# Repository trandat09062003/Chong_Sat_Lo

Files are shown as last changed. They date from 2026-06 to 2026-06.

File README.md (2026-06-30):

# Hệ thống cảnh báo sạt lở đất (Chong_Sat_Lo)

Dự án nghiên cứu thiết kế và chế tạo trạm đo thực địa cảnh báo sớm nguy cơ sạt lở đất tại các vùng đồi núi (đặc biệt áp dụng thử nghiệm tại khu vực Dốc Cun và Đèo Thung Khe, Quốc lộ 6, tỉnh Hòa Bình) dựa trên các thông số môi trường và động học đất.

Hệ thống bao gồm các trạm đo thực địa (mạch phát) thu thập dữ liệu đa cảm biến, tự động đánh giá nguy cơ sạt lở và gửi thông tin không dây qua sóng LoRa khoảng cách xa về trạm giám sát (mạch thu).

---

## 1. Thành phần hệ thống

### Trạm đo thực địa (Mạch Phát - Transmit)
- **MCU trung tâm:** ESP32 DevKit V1 (30 chân).
- **Cảm biến địa chấn & động học:** MPU6050 đo rung chấn, góc nghiêng và độ dịch chuyển cấu trúc đất.
- **Cảm biến môi trường:** Cảm biến độ ẩm đất (giám sát độ bão hòa nước) và cảm biến lượng mưa.
- **Khối hiển thị:** Màn hình LCD 20x4 giao tiếp I2C.
- **Khối truyền thông:** Module LoRa SX1278 (E32/AS32 UART) truyền xa.
- **Khối cảnh báo:** Còi hú cảnh báo tại chỗ kích bằng transistor C1815.
- **Khối nguồn:** Pin Lithium 18650 sạc bằng năng lượng mặt trời (tấm pin 5V - 10W qua mạch sạc TP4056) và cầu phân áp đo dung lượng pin gửi về trung tâm.

### Trạm giám sát (Mạch Thu - Receive)
- **MCU trung tâm:** ESP32 nhận dữ liệu LoRa gửi về.
- **Hiển thị tại chỗ:** Màn hình LCD 20x4 I2C hiển thị trực quan thông số nhận được từ trạm phát.
- **Dashboard Web:** ESP32 mạch thu tự phát mạng Wi-Fi Access Point cục bộ (`ESP32_Gateway_AP`) và khởi chạy Web Server hiển thị giao diện dashboard giám sát thời gian thực, có chế độ chớp đỏ và còi báo động trên web khi trạm phát rơi vào trạng thái nguy hiểm.

---

## 2. Sơ đồ kết nối phần cứng (Theo code thực tế)

### Mạch Phát (Transmit Node)
| Thiết bị / Chân kết nối | Chân ESP32 | Ghi chú |
| --- | --- | --- |
| **Cảm biến độ ẩm đất (Analog)** | GPIO 34 | Đọc giá trị ADC độ bão hòa nước |
| **Cảm biến độ ẩm đất (Digital)** | GPIO 35 | Phát hiện ngưỡng khô/ẩm |
| **Cảm biến mưa (Analog)** | GPIO 33 | Đọc giá trị ADC cường độ mưa |
| **Cảm biến mưa (Digital)** | GPIO 32 | Phát hiện có mưa hay không |
| **Cảm biến MPU6050 (I2C SDA)** | GPIO 21 | Bus dữ liệu I2C dùng chung với LCD |
| **Cảm biến MPU6050 (I2C SCL)** | GPIO 22 | Bus xung clock I2C |
| **Cảm biến MPU6050 (INT)** | GPIO 4 | Chân ngắt tín hiệu địa chấn |
| **Màn hình LCD 20x4 I2C** | GPIO 21 (SDA), GPIO 22 (SCL) | Địa chỉ mặc định: 0x27 |
| **Còi hú (Buzzer)** | GPIO 25 | Kích hoạt còi hú mức cao (HIGH) |
| **Đo điện áp Pin** | GPIO 12 | Đọc qua cầu phân áp R1=100k, R2=100k |
| **LoRa E32/AS32 (RX)** | GPIO 16 | Nối với chân TX của module LoRa |
| **LoRa E32/AS32 (TX)** | GPIO 17 | Nối với chân RX của module LoRa |
| **LoRa E32/AS32 (M0/M1/AUX)**| GPIO 26 / 27 / 14 | Điều khiển chế độ hoạt động của LoRa |

### Mạch Thu (Receive Node)
| Thiết bị / Chân kết nối | Chân ESP32 | Ghi chú |
| --- | --- | --- |
| **LoRa E32/AS32 (RX)** | GPIO 16 | Nối với chân TX của module LoRa |
| **LoRa E32/AS32 (TX)** | GPIO 17 | Nối với chân RX của module LoRa |
| **LoRa E32/AS32 (M0/M1/AUX)**| GPIO 25 / 26 / 27 | Điều khiển chế độ hoạt động |
| **LCD 20x4 I2C** | GPIO 21 (SDA), GPIO 22 (SCL) | Hiển thị thông số nhận được từ RF |

---

## 3. Cấu trúc thư mục dự án

```text
├── Transmit/                  # Mã nguồn trạm phát đo thực địa (Transmit.ino)
├── Receive/                   # Mã nguồn trạm thu (Receive.ino)
├── PCB_Tra/                   # Bản vẽ Altium Designer trạm phát (Schematic & PCB)
├── PCB_Rec/                   # Bản vẽ Altium Designer trạm thu (Schematic & PCB)
├── libraries/                 # Thư viện Arduino đóng gói dùng chung cho dự án
├── Test_*/                    # Các thư mục chứa mã nguồn test độc lập linh kiện
│   ├── Test_Buzzer/
│   ├── Test_LoRa_E32/
│   └── Test_MPU_LCD/
├── yêu cầu.txt                # Tài liệu tóm tắt yêu cầu dự án
└── Báo cáo tuần 5.docx        # Báo cáo tiến độ và kết quả thực hiện tuần 5
```

---

## 4. Logic phân cấp cảnh báo (Risk Evaluation)

Thuật toán đánh giá rủi ro kết hợp các ngưỡng giá trị môi trường và gia tốc/góc nghiêng để đưa ra 3 cấp độ cảnh báo:

1. **Cấp độ 0 (AN TOÀN - SAFE):** 
   - Đất ổn định, không mưa, góc nghiêng và độ rung lắc dưới ngưỡng cảnh báo.
2. **Cấp độ 1 (CẢNH BÁO SỚM - WARNING):**
   - Xảy ra khi độ ẩm đất tăng cao (`>= 70%`), mưa kéo dài (`>= 60%`) hoặc xuất hiện rung lắc nhẹ (`>= 0.8 m/s²`).
3. **Cấp độ 2 (NGUY HIỂM - DANGER):**
   - Phát hiện sụt lún hoặc trượt đất tức thời khi góc nghiêng lệch quá ngưỡng (`>= 15 độ`), hoặc đất đã bão hòa nước cực cao (`>= 85%`) kèm rung chấn địa chất mạnh (`>= 1.5 m/s²`).
   - Hệ thống tự kích hoạt còi hú cảnh báo tại chỗ đồng thời gửi tín hiệu khẩn cấp về trạm thu qua LoRa.

---

## 5. Hướng dẫn cài đặt và sử dụng

### Cài đặt phần mềm
1. Sao chép các thư mục con trong thư mục `libraries/` của dự án vào thư mục `libraries` trong thư mục làm việc của Arduino IDE trên máy tính.
2. Mở file mã nguồn `Transmit/Transmit.ino` (cho mạch phát) hoặc `Receive/Receive.ino` (cho mạch thu) bằng Arduino IDE.
3. Chọn đúng board `DOIT ESP32 DEVKIT V1` (hoặc `ESP32 Dev Module`) và cổng COM để nạp chương trình.

### Vận hành hệ thống
1. **Trạm phát:** Đặt thiết bị cố định trên cọc cắm sâu dưới đất tại khu vực cần theo dõi. Khi cấp nguồn, hệ thống sẽ tự động đo đạc góc cân bằng ban đầu (Pitch/Roll) làm mốc so sánh.
2. **Trạm thu:** Đặt tại phòng điều khiển hoặc khu vực trung tâm. Trạm thu sẽ liên tục cập nhật dữ liệu hiển thị lên LCD.
3. **Giám sát qua Web:** Kết nối điện thoại hoặc máy tính vào mạng Wi-Fi `ESP32_Gateway_AP` (mật khẩu: `123456789_landslide`). Truy cập địa chỉ IP `192.168.4.1` trên trình duyệt để xem giao diện dashboard.

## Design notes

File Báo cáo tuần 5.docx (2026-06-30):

1. Sơ đồ khối

Khối nguồn (tấm pin NLMT)

Khối cảm biến

Mạch đo dung luọng pin

Khối xử lý

(ESP32)

Khối truyền tin (loRa)

Khối hiển thị

Khối cảnh báo

Trung tâm giám sát và điều hành

Tín hiệu nối cứng

Tín hiệu không dây

Đường nguồn

- Khối nguồn: cấp điện cho toàn bộ hệ thống trên sơ đồ có các mức điện áp sau

+ 3.3V: dùng cho khối cảm biến, khối xử lý, khối truyền tin

+ 5V: dùng cho khối cảm biến khối hiển thị khối cảnh báo và 1 số thiết bị khác

- Khối cảm biến: sau khi đo độ ẩm đất, lượng mưa và độ rung xong sẽ gửi tín hiệu đến khối xử lý
- Khối xử lý: sau khi đã nhận dữ liệu từ khối cảm biến sẽ tiến hành đánh giá, xử lý dựa trên kết quả đo được và đưa ra cảnh báo
- Mạch đo dung lượng pin: giúp trung tâm giám sát và điều hành biết được pin còn lại bao nhiêu % và điện áp của pin như nào
- Khối hiển thị: hiển thị dữ liệu cảm biến do được và điện áp pin
- Khối lora: truyền dữ liệu cảm biến dung lượng pin trạng thái cảnh báo về trung tâm giám sát và nguọc lại
- Khói cảnh báo: cảnh báo khu vực có nguy cơ sạt lở
- Trung tâm giám sát điều hành: nhận tất cả dữ liệu trên đưa ra cảnh báo và sợ tán người dân phương tiện trước khi sảy ra sạt lở

Giao tiếp giữa các khối

- Khối cảm biến giao tiếp với ESP32

+ cảm biến lượng mưa vs esp32 qua Analog/Digital

+ cảm biến độ ẩm đất vs esp32 qua Analog

+ cẩm biến rung(MPU6050) vs esp32 qua I2C

- Khối truyền tin lora giao tiếp vs esp32 qua SPI
- Khối hiển thị giao tiếp vs esp32 qua I2C
- Khối cảnh báo giao tiếp vs esp32 qua Digital
- Mạch đo pin giao tiếp vs esp32 qua
2. Bảng dự toán và chức năng của linh kiện

STT | Tên linh kiện | Chức năng trong đồ án | Số lượng | Đơn giá (VNĐ) | Thành tiền (VNĐ)
1 | ESP32 | Vi điều khiển trung tâm, xử lý dữ liệu và kết nối. | 2 | 120.000 | 240.000
2 | Module LoRa SX1278 (433MHz) | Truyền/Nhận dữ liệu không dây khoảng cách xa. | 2 | 200.000 | 400.000
3 | Cảm biến lượng mưa | Đo cường độ và lượng mưa rơi xuống. | 1 | 75.000 | 75.000
4 | Cảm biến độ ẩm đất | Giám sát độ bão hòa nước của đất vùng núi. | 1 | 75.000 | 75.000
5 | Cảm biến MPU6050 | Đo độ rung, độ nghiêng và dịch chuyển của đất. | 1 | 90.000 | 90.000
6 | Tấm pin năng lượng mặt trời (5V-10W) | Cung cấp năng lượng cho hệ thống ngoài thực địa. | 2 | 200.000 | 400.000
7 | Pin Lithium 18650 & Mạch sạc TP4056 | Lưu trữ năng lượng và quản lý sạc/xả pin. | 2 | 60.000 | 120.000
8 | Còi hú cảnh báo | Phát tín hiệu cảnh báo tại chỗ cho người đi đường. | 1 | 55 .000 | 55.000
9 | Màn hình LCD 16x2 (I2C) | Hiển thị thông số môi trường tại trạm. | 1 | 150.000 | 150.000
10 | Phụ kiện khác | Bảo vệ hệ thống khỏi thời tiết và kết nối linh kiện. | 1 | 500.000 | 500.000

Tổng cộng: ~2.105.000VND

3. Tại sao lại dùng esp32 làm vđk trung tâm
- Hiệu năng mạnh, xử lý đa cảm biến tốt

+ ESP32 có CPU 32-bit, tốc độ cao (~240MHz)

+ Đọc nhiều cảm biến cùng lúc: mưa, độ ẩm đất, MPU6050 (rung)

- Tích hợp nhiều giao tiếp (rất quan trọng)

+ đọc MPU6050, LCD

+ giao tiếp SX1278 LoRa Module

- Tiết kiệm điện (có chế độ Deep Sleep)

+ Có thể giảm tiêu thụ xuống rất thấp khi không hoạt động

+ Phù hợp với hệ thống dùng pin năng lượng mặt trời

- Dù hiện tại không dùng WiFi, nhưng:

+ ESP32 đã tích hợp WiFi + Bluetooth sẵn Sau này có thể:

+ Gửi dữ liệu lên app

+ Kết nối IoT (Blynk, web server…)

+ Tận dụng hiệu năng, tiết kiệm điện và khả năng mở rộng IoT trong tương lai

4. Nghiên cứu mô hình dự báo khả năng sạt lở (các đầu vào, mô hình dự báo, tỷ lệ chính xác)
- Các đầu vào của hệ thống dự báo nên chia thành 3 nhóm:

+ Nhóm khí tượng:

• Lượng mưa (mm/h, mm/ngày)

• Thời gian mưa liên tục

+ Nhóm địa chất – môi trường

• Độ ẩm đất (%)

• Độ bão hòa nước trong đất

+ Nhóm động học (chuyển động)

• Gia tốc/rung động đất (từ MPU6050)

• Độ nghiêng địa hình (nếu có)

- Sử dụng mô hình ngưỡng cảnh báo (Threshold-based Model)
- Hệ thống sẽ đọc lượng mưa, độ ẩm đất, và độ rung sau đấy sẽ gửi dữ liệu về cho ESP32 kiểm tra kết hợp với thông số đo được từ nhiều lần sạt lở trước để đưa ra mức độ cảnh báo trung bình cho những lần sắp tới

+ Ví dụ mức trung bình:

• Mưa > 50 mm/ngày

• Độ ẩm đất > 70%

• Có rung bất thường

+ Nếu các thông số sau vượt mức trung bình trên hệ thống sẽ gửi tín hiệu cảnh báo sạt lở về trung tâm

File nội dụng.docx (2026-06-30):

1. Cảm biến địa chấn để giám sát động học đất

Tích hợp cảm biến địa chấn để giám sát động học đất

Để hệ thống cảnh báo sạt lở đạt được độ tin cậy cao, việc chỉ đo lường các thông số môi trường tĩnh (như lượng mưa hay độ ẩm đất) là chưa đủ, bởi chúng chỉ phản ánh các điều kiện tiền đề. Nhằm phát hiện trực tiếp các dấu hiệu sạt lở đang nhen nhóm, đề tài tiến hành bổ sung cảm biến quán tính 6 trục MPU6050 đóng vai trò như một cảm biến địa chấn (seismic sensor) cục bộ. Nhiệm vụ của khối này là giám sát liên tục các đặc trưng động học như sự dịch chuyển, rung chấn và đứt gãy vật lý của cấu trúc đất đá.

Giải pháp phần cứng và phương pháp đo lường:

- Lắp đặt thực địa: Module MPU6050 được gắn cố định bên trong một cọc quan trắc chuyên dụng và đóng ngập sâu xuống lớp đất chịu lực tại sườn dốc. Việc neo chặt khối cảm biến vào nền đất giúp thiết bị nhạy bén tuyệt đối với những dao động cơ học truyền qua khối đất.
- Giao tiếp dữ liệu: Cảm biến giao tiếp với bộ vi điều khiển trung tâm (ESP32) thông qua chuẩn nối tiếp I2C. Vi điều khiển được lập trình để liên tục lấy mẫu dữ liệu không gian 3 chiều với tần số cao, đảm bảo không bỏ sót bất kỳ rung động chớp nhoáng nào của nền đất.

Thuật toán xử lý tín hiệu và lọc nhiễu:

- Loại bỏ nhiễu môi trường: Dữ liệu gia tốc thô thu về ở thực địa thường bị lẫn các nhiễu cơ học không mong muốn (như sức gió tạt vào thân cọc lộ thiên hoặc chấn động từ phương tiện giao thông đi ngang qua). Để làm sạch dữ liệu, hệ thống kích hoạt bộ lọc thông thấp kỹ thuật số (DLPF) tích hợp sẵn bên trong cảm biến nhằm triệt tiêu các dải tần số nhiễu cao, chỉ giữ lại các dao động tần số thấp phản ánh đúng bản chất sự chuyển dịch của khối đất.
- Đánh giá mức độ rủi ro động học: Thay vì đánh giá rời rạc sự thay đổi trên từng trục tọa độ (X, Y, Z), vi điều khiển sẽ thuật toán hóa để tổng hợp các giá trị này lại, từ đó xác định được biên độ chuyển động tổng thể và độ lệch góc nghiêng thực tế của cọc quan trắc.
- Phát hiện bất thường: Ở trạng thái an toàn, cấu trúc đất ổn định, hệ thống cảm biến chỉ ghi nhận duy nhất tác động của gia tốc trọng trường và góc nghiêng được duy trì hằng số. Khi kết cấu đất ngậm đủ nước và bắt đầu có hiện tượng sụt lún, trượt hoặc nứt gãy bên trong, biên độ dao động tổng thể sẽ thay đổi đột ngột. Những biến thiên vượt qua dải sai số tĩnh cho phép này sẽ được hệ thống nhận diện là đặc trưng nguy hiểm, sau đó được trích xuất làm đầu vào cho mô hình dự báo học máy để xác định thời điểm kích hoạt báo động khẩn cấp.

2. Thu thập dữ liệu tình hình sạt lở tại địa phương cụ thể

Để hệ thống cảnh báo có tính ứng dụng thực tiễn cao và mô hình dự báo học máy hoạt động chính xác, việc xây dựng một bộ dữ liệu (dataset) dựa trên bối cảnh địa chất thực tế là yêu cầu bắt buộc. Đề tài lựa chọn phạm vi nghiên cứu và thu thập dữ liệu tại tuyến Quốc lộ 6, đoạn qua Dốc Cun và Đèo Thung Khe thuộc tỉnh Hòa Bình.

Đặc điểm địa chất khu vực nghiên cứu: Đây là tuyến giao thông huyết mạch cửa ngõ vùng Tây Bắc, có địa hình đồi núi chia cắt phức tạp và độ dốc sườn taluy rất lớn. Kết cấu đất đá tại khu vực này bị phong hóa mạnh, tơi xốp, hệ số rỗng lớn và có độ liên kết kém. Vào mùa mưa bão, khi lớp đất mặt ngậm nước đến mức bão hòa, trọng lượng khối trượt tăng lên đột biến trong khi lực ma sát nội suy giảm, biến khu vực này thành "điểm nóng" nhạy cảm, thường xuyên xảy ra sụt lún và sạt lở đất đá nghiêm trọng.

Quy trình và phương pháp thu thập dữ liệu: Do không có điều kiện cắm trạm đo trực tiếp trong thời gian dài (nhiều năm), đề tài sử dụng phương pháp thu thập dữ liệu thứ cấp từ cơ sở dữ liệu của các cơ quan chuyên môn. Quá trình thu thập tập trung vào các nhóm thông tin sau:

- Dữ liệu khí tượng: Thu thập số liệu về lượng mưa tích lũy (theo giờ và theo ngày), độ ẩm không khí trong các tháng mùa mưa từ các trạm quan trắc khí tượng thủy văn khu vực tỉnh Hòa Bình.
- Dữ liệu lịch sử thiên tai: Trích xuất từ các báo cáo tổng kết của Ban Chỉ huy Phòng chống thiên tai và Tìm kiếm cứu nạn tỉnh Hòa Bình, kết hợp với hồ sơ sự cố của cơ quan quản lý đường bộ để lập danh sách các mốc thời gian (ngày, giờ cụ thể), vị trí và quy mô của các vụ sạt lở đã từng xảy ra trên tuyến đường này trong quá khứ.

Tiền xử lý và gán nhãn dữ Chuỗi số liệu khí tượng và lịch sử sạt lở sau khi thu thập sẽ được đồng bộ hóa theo trục thời gian để xây dựng thành một cấu trúc dữ liệu dạng bảng. Dựa trên việc đối chiếu thời điểm xảy ra sự cố sạt lở với các thông số môi trường trước đó (ví dụ: đã mưa liên tục bao nhiêu ngày, lượng mưa tích lũy đạt mức nào), tập dữ liệu sẽ được dán nhãn (labeling) thành các cấp độ rủi ro tương ứng: Trạng thái an toàn, Trạng thái nguy cơ và Trạng thái báo động.

Bộ dữ liệu hoàn chỉnh mang tính đặc trưng của địa phương này sẽ đóng vai trò là "kinh nghiệm" đầu vào để huấn luyện thuật toán phân loại học máy. Nhờ đó, hệ thống vi điều khiển có khả năng nhận diện các khuôn mẫu thời tiết nguy hiểm tương tự để đưa ra quyết định hú còi cảnh báo một cách tự động và chính xác.

3. Mô hình máy học (Machine Learning) ứng dụng dự báo

Đề tài ứng dụng thuật toán học máy có giám sát, cụ thể là mô hình Thuật toán Random Forests (Random Forest Classifier). Điểm đột phá của hệ thống là mô hình này được triển khai theo kiến trúc Trí tuệ nhân tạo tại biên (TinyML / Edge AI), cho phép nhúng trực tiếp khối tính toán suy luận vào bộ nhớ của vi điều khiển trung tâm tại trạm quan trắc.

Lý do lựa chọn thuật toán Random Forest:

- Phù hợp với đặc thù dữ liệu: Dữ liệu thu thập từ các cảm biến (mưa, ẩm, độ rung) là dữ liệu dạng bảng. Thuật toán Rừng ngẫu nhiên – bản chất là sự kết hợp của tập hợp nhiều Cây quyết định (Decision Trees) – hoạt động cực kỳ hiệu quả với loại dữ liệu này. Nó có khả năng tự động tìm ra các quy luật phức tạp, xử lý tốt các mối quan hệ phi tuyến giữa tác động của môi trường và sự suy yếu của nền đất, đồng thời rất bền bỉ trước các tín hiệu nhiễu hoặc sai số cục bộ từ cảm biến.
- Tối ưu tài nguyên phần cứng: Một trong những rào cản lớn nhất của học máy là yêu cầu cấu hình máy tính cao. Tuy nhiên, khi mô hình Rừng ngẫu nhiên được huấn luyện xong và biên dịch sang ngôn ngữ C/C++, nó chủ yếu tồn tại dưới dạng các mảng cấu trúc và tập lệnh rẽ nhánh logic. Điều này giúp mô hình tiêu tốn một lượng rất nhỏ bộ nhớ Flash và RAM, cho phép thực thi mượt mà trên vi điều khiển ESP32 mà không làm ảnh hưởng đến các tác vụ khác.

Cấu trúc dữ liệu và phân loại rủi ro:

- Đặc trưng đầu vào (Input Features): Mô hình liên tục tiếp nhận và phân tích các biến số độc lập được cập nhật theo thời gian thực. Các biến này bao gồm: độ bão hòa nước trong đất hiện tại, lượng mưa tích lũy trong một khung thời gian nhất định, và biên độ dao động cơ học tổng hợp trích xuất từ khối cảm biến địa chấn.
- Phân loại đầu ra (Output Labels): Dựa trên các đặc trưng đầu vào và đối chiếu với "kinh nghiệm" từ bộ dữ liệu lịch sử đã được huấn luyện, thuật toán sẽ tính toán và phân loại tình trạng sườn dốc thành ba cấp độ: Trạng thái an toàn, Trạng thái cảnh báo sớm (đất bắt đầu bão hòa nước, cần theo dõi), và Trạng thái nguy hiểm (rủi ro sạt lở tức thời).

Ưu điểm của phương pháp xử lý tại biên (Edge Inference): Việc đưa trí tuệ nhân tạo xuống thực thi trực tiếp tại node cảm biến mang lại độ tin cậy tuyệt đối cho hệ thống cảnh báo thiên tai. Khối lượng tính toán rủi ro được giải quyết ngay tại hiện trường giúp hệ thống phản hồi không có độ trễ (Real-time). Hơn thế nữa, phương pháp này khắc phục được điểm yếu chí mạng của các hệ thống IoT phụ thuộc vào máy chủ đám mây: trạm quan trắc vẫn duy trì khả năng tự động phân tích và kích hoạt còi hú tại chỗ ngay cả khi mạng lưới truyền tin vô tuyến (LoRa) bị tê liệt do giông lốc hoặc vật cản địa hình.

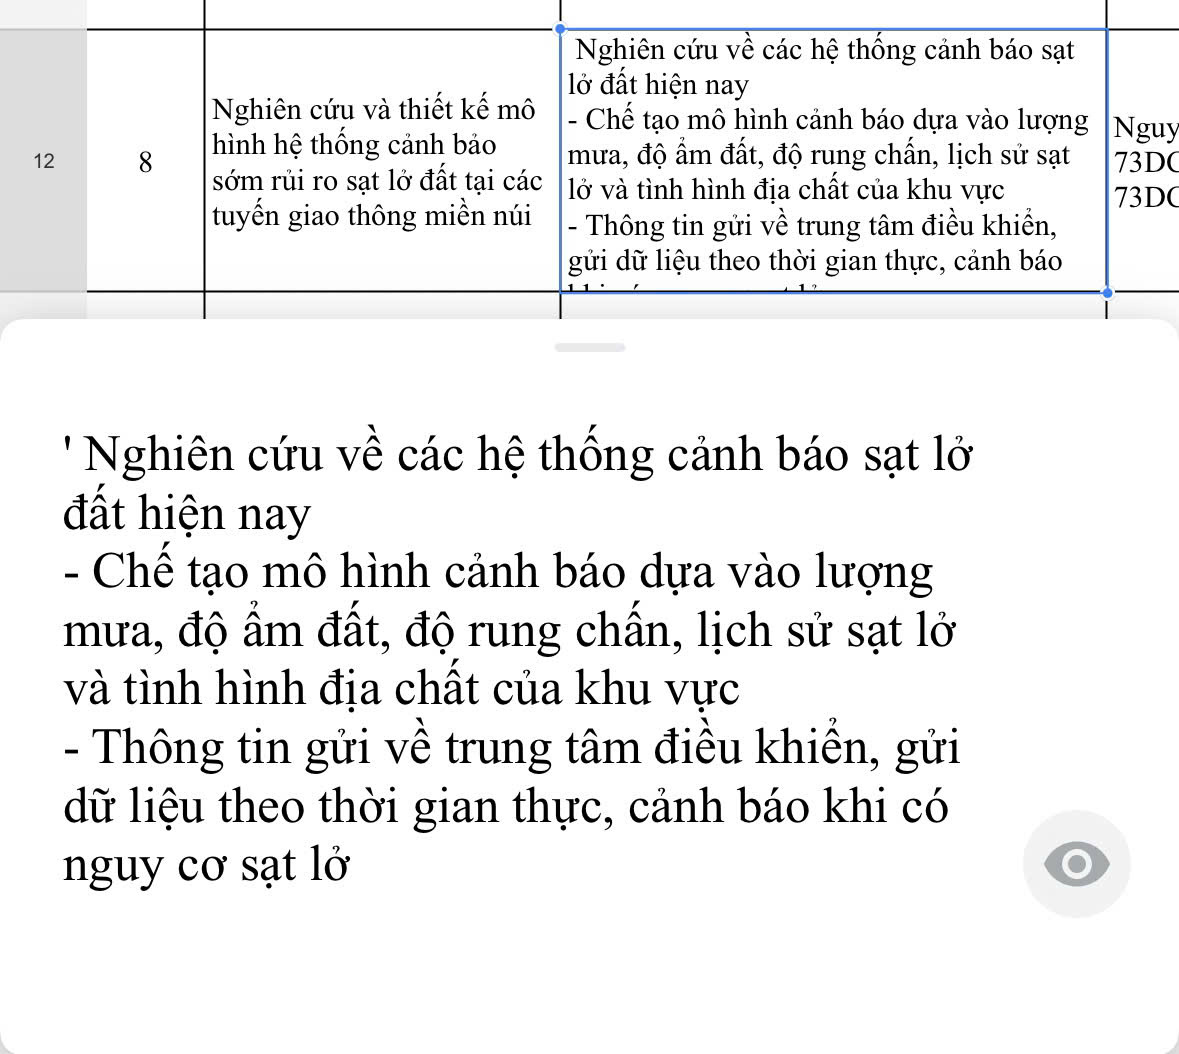
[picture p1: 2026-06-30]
z7881662211903_ccd41fbca4f645adeecdb2058f0969e3.jpg

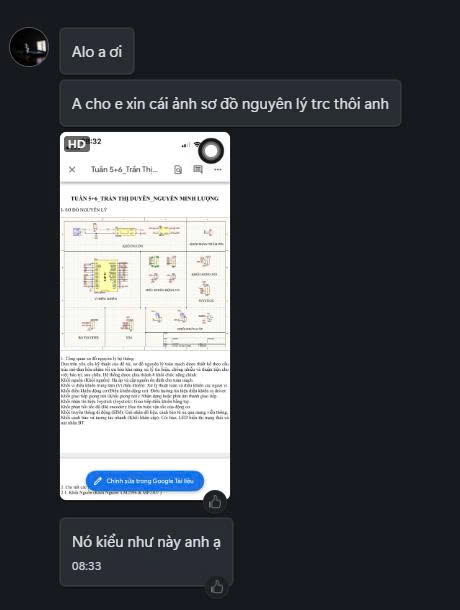
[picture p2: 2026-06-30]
z7881663986014_13d9347bac7c115efbf705733440d59f.jpg

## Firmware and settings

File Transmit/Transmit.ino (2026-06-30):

/*
 * Transmit.ino - Mạch phát cảnh báo sạt lở đất (Anti-Landslide Transmitter Node)
 * Sử dụng vi điều khiển ESP32 DevKit V1 (30 chân) làm bộ xử lý trung tâm
 * 
 * Sơ đồ kết nối phần cứng theo mạch nguyên lý:
 * - Cảm biến độ ẩm đất (Soil Moisture):
 *   + SOIL_AO -> GPIO 34 (ADC1_CH6)
 *   + SOIL_DO -> GPIO 35 (Digital Input)
 * - Cảm biến mưa (Rain Sensor):
 *   + RAIN_AO -> GPIO 33 (ADC1_CH5)
 *   + RAIN_DO -> GPIO 32 (Digital Input)
 * - Cảm biến MPU6050 (Gia tốc & Góc nghiêng):
 *   + I2C SCL -> GPIO 22
 *   + I2C SDA -> GPIO 21
 *   + MPU_INT -> GPIO 4
 * - Màn hình LCD 16x2 (giao tiếp qua I2C):
 *   + SCL -> GPIO 22
 *   + SDA -> GPIO 21
 * - Mạch đo dung lượng pin:
 *   + BAT_ADC -> GPIO 12 qua cầu phân áp R1=100k, R2=100k
 * - Khối cảnh báo (Còi hú):
 *   + BUZZER_CTRL -> GPIO 25
 * - LoRa E32/AS32 UART (PCB phat):
 *   + M0=26, M1=27, AUX=14, RX=16 (RX2<-LORA_TX), TX=17 (TX2->LORA_RX)
 */

#include <Wire.h>
#include <LiquidCrystal_I2C.h>
#include <Adafruit_MPU6050.h>
#include <Adafruit_Sensor.h>
#include <LoRaLink.h>
#define E32_M0_PIN    26
#define E32_M1_PIN    27
#define E32_AUX_PIN   14
#define E32_RX_PIN    16
#define E32_TX_PIN    17
#include <LoRaUartE32.h>

// Định nghĩa các chân kết nối cảm biến
#define SOIL_AO_PIN    34
#define SOIL_DO_PIN    35
#define RAIN_AO_PIN    33
#define RAIN_DO_PIN    32
#define BAT_ADC_PIN    12
#define BUZZER_PIN     25

// Cấu hình bus I2C dùng chung cho LCD 2004 và MPU6050
#define I2C_SDA_PIN    21
#define I2C_SCL_PIN    22
#define I2C_CLOCK_HZ   100000  // 100kHz ổn định khi nhiều thiết bị trên cùng bus

// Khởi tạo các đối tượng
LiquidCrystal_I2C lcd(0x27, 20, 4); // Địa chỉ I2C mặc định của LCD 2004 là 0x27, kích thước 20x4
Adafruit_MPU6050 mpu;
LoRaUartE32 loraRadio;
bool loraReady = false;

// Các ngưỡng cảnh báo mặc định (dùng để hiệu chuẩn và phân loại mức độ rủi ro)
const int MOISTURE_THRESHOLD_DRY = 3200; // Giá trị ADC khô (càng khô ADC càng cao)
const int MOISTURE_THRESHOLD_WET = 1200; // Giá trị ADC ẩm ướt
const int RAIN_THRESHOLD_HEAVY   = 1500; // Giá trị ADC mưa lớn (càng mưa lớn ADC càng nhỏ)
const float TILT_THRESHOLD_DEG   = 15.0; // Ngưỡng góc nghiêng cảnh báo nguy hiểm (độ)
const float VIBRATION_THRESHOLD  = 1.5;  // Ngưỡng rung lắc gia tốc cảnh báo (m/s^2)

// Các biến lưu giá trị lọc
float basePitch = 0.0;
float baseRoll = 0.0;
bool mpuInitialized = false;

// Trạng thái cảnh báo: 0 = An toàn, 1 = Cảnh báo sớm, 2 = Nguy hiểm
uint8_t currentAlertLevel = 0; 
unsigned long lastLoraSendTime = 0;
unsigned long lastSerialLogTime = 0;
const unsigned long LORA_SEND_INTERVAL = 3000;
const unsigned long SERIAL_LOG_INTERVAL = 3000;

static bool g_buzzerOn = false;

void buzzerOn() {
  if (g_buzzerOn) {
    return;
  }
#if defined(ESP32) && defined(SOC_DAC_SUPPORTED)
  dacDisable(BUZZER_PIN);
#endif
  pinMode(BUZZER_PIN, OUTPUT);
  digitalWrite(BUZZER_PIN, HIGH);
  g_buzzerOn = true;
}

void buzzerOff() {
  if (!g_buzzerOn) {
    return;
  }
  digitalWrite(BUZZER_PIN, LOW);
  g_buzzerOn = false;
}

void buzzerSelfTest() {
  Serial.println("[BUZZER] Test GPIO25...");
  buzzerOn();
  delay(300);
  buzzerOff();
}

void initBuzzer() {
  buzzerOff();
#if defined(ESP32) && defined(SOC_DAC_SUPPORTED)
  dacDisable(BUZZER_PIN);
#endif
  pinMode(BUZZER_PIN, OUTPUT);
  digitalWrite(BUZZER_PIN, LOW);
}

void updateBuzzer(uint8_t alertLevel) {
  if (alertLevel == 2) {
    buzzerOn();
  } else {
    buzzerOff();
  }
}
// Khởi tạo bus I2C với chân và tốc độ cố định (dùng chung LCD + MPU6050)
void initI2CBus() {
  Wire.begin(I2C_SDA_PIN, I2C_SCL_PIN);
  Wire.setClock(I2C_CLOCK_HZ);
#if defined(WIRE_HAS_TIMEOUT)
  Wire.setTimeOut(1000);
#endif
}

// Kiểm tra thiết bị có phản hồi tại địa chỉ I2C không
bool probeI2C(uint8_t address) {
  Wire.beginTransmission(address);
  return Wire.endTransmission() == 0;
}

// Đánh thức MPU6050 khỏi chế độ sleep trước khi Adafruit library khởi tạo
void wakeMPU6050(uint8_t address) {
  Wire.beginTransmission(address);
  Wire.write(0x6B); // PWR_MGMT_1
  Wire.write(0x00); // Bật clock, thoát sleep
  Wire.endTransmission();
  delay(50);
}

// Quét và in các địa chỉ I2C (hỗ trợ chẩn đoán lỗi phần cứng)
void scanI2CBus() {
  Serial.println("[I2C] Dang quet bus (SDA=21, SCL=22)...");
  int found = 0;
  for (uint8_t addr = 1; addr < 127; addr++) {
    if (probeI2C(addr)) {
      Serial.printf("  + Thiet bi tai 0x%02X", addr);
      if (addr == 0x27 || addr == 0x3F) Serial.print(" (LCD)");
      else if (addr == 0x68 || addr == 0x69) Serial.print(" (MPU6050)");
      Serial.println();
      found++;
    }
  }
  if (found == 0) {
    Serial.println("  ! Khong tim thay thiet bi I2C nao!");
  }
}

// Khởi tạo MPU6050: thử 0x68 (AD0=LOW) rồi 0x69 (AD0=HIGH)
bool initMPU6050() {
  const uint8_t addresses[] = {0x68, 0x69};
  for (uint8_t addr : addresses) {
    if (!probeI2C(addr)) {
      continue;
    }
    initI2CBus();
    wakeMPU6050(addr);
    initI2CBus();
    if (mpu.begin(addr, &Wire)) {
      Serial.printf("[SYSTEM] MPU6050 ket noi tai dia chi 0x%02X\n", addr);
      return true;
    }
  }
  return false;
}

void setup() {
  // Cấu hình Serial debug
  Serial.begin(9600);
  delay(500);
  Serial.println("\n--- KHOI DONG MACH PHAT CANH BAO SAT LO ---");

  initBuzzer();

  // Cấu hình các chân Digital Input/Output
  pinMode(SOIL_DO_PIN, INPUT);
  pinMode(RAIN_DO_PIN, INPUT);

  // Khởi tạo bus I2C trước
  initI2CBus();
  delay(100); // Đợi MPU6050 ổn định sau cấp nguồn
  scanI2CBus();

  // Khởi tạo MPU6050 trước khi LCD chiếm bus I2C
  if (initMPU6050()) {
    mpu.setAccelerometerRange(MPU6050_RANGE_8_G);
    mpu.setGyroRange(MPU6050_RANGE_500_DEG);
    mpu.setFilterBandwidth(MPU6050_BAND_21_HZ);
    mpuInitialized = true;
    calibrateMPU();
  } else {
    Serial.println("[WARNING] Khong tim thay MPU6050! Vui long kiem tra ket noi I2C.");
    Serial.println("  -> Kiem tra VCC/GND, SDA(21), SCL(22), chan AD0 cua MPU6050.");
  }

  // Khởi tạo LCD sau MPU6050 (cùng bus I2C 0x27)
  initI2CBus();
  lcd.init();
  lcd.backlight();
  lcd.setCursor(0, 0);
  lcd.print("ANTI-LANDSLIDE");
  lcd.setCursor(0, 1);
  if (mpuInitialized) {
    lcd.print("MPU6050: OK     ");
  } else {
    lcd.print("MPU6050: ERROR! ");
  }
  delay(1000);
  lcd.clear();

  // LoRa khoi tao cuoi
  Serial.println("[SYSTEM] Dang khoi tao LoRa E32/AS32...");
  delay(100);
  loraRadio.begin();
  loraRadio.configureModule();
  loraReady = true;
  Serial.println("[SYSTEM] LoRa san sang phat RF.");

  initBuzzer();
  buzzerSelfTest();

  lastSerialLogTime = millis() - SERIAL_LOG_INTERVAL;
  lastLoraSendTime = millis();
  Serial.println("[SYSTEM] Khoi dong xong. Doc cam bien moi 3 giay.");
}

void loop() {
  // 1. Đọc dữ liệu từ cảm biến độ ẩm đất
  int soilAnalog = analogRead(SOIL_AO_PIN);
  int soilDigital = digitalRead(SOIL_DO_PIN);
  // Quy đổi độ ẩm đất ra % (ADC cao = đất khô, ADC thấp = đất ẩm)
  float soilPercent = map(soilAnalog, MOISTURE_THRESHOLD_DRY, MOISTURE_THRESHOLD_WET, 0, 100);
  soilPercent = constrain(soilPercent, 0.0, 100.0);

  // 2. Đọc dữ liệu từ cảm biến mưa
  int rainAnalog = analogRead(RAIN_AO_PIN);
  int rainDigital = digitalRead(RAIN_DO_PIN);
  // Quy đổi lượng mưa ra % (ADC cao = không mưa, ADC thấp = mưa to)
  float rainPercent = map(rainAnalog, 4095, RAIN_THRESHOLD_HEAVY, 0, 100);
  rainPercent = constrain(rainPercent, 0.0, 100.0);

  // 3. Đọc dữ liệu MPU6050 (độ nghiêng và rung chấn)
  float pitch = 0.0;
  float roll = 0.0;
  float tiltAngle = 0.0;
  float vibration = 0.0;

  if (mpuInitialized) {
    sensors_event_t a, g, temp;
    mpu.getEvent(&a, &g, &temp);

    // Tính toán góc nghiêng Pitch và Roll từ gia tốc trọng trường
    pitch = atan2(-a.acceleration.x, sqrt(a.acceleration.y * a.acceleration.y + a.acceleration.z * a.acceleration.z)) * 180.0 / M_PI;
    roll = atan2(a.acceleration.y, a.acceleration.z) * 180.0 / M_PI;

    // Độ lệch góc so với trạng thái cân bằng ban đầu
    float deltaPitch = abs(pitch - basePitch);
    float deltaRoll = abs(roll - baseRoll);
    tiltAngle = max(deltaPitch, deltaRoll);

    // Tính toán mức độ rung động (vibration) thông qua độ lệch gia tốc tổng hợp
    float totalAcc = sqrt(a.acceleration.x * a.acceleration.x + 
                          a.acceleration.y * a.acceleration.y + 
                          a.acceleration.z * a.acceleration.z);
    vibration = abs(totalAcc - 9.81); // Trừ đi gia tốc trọng trường chuẩn g = 9.81 m/s^2
  }

  // 4. Đo điện áp pin và tính dung lượng pin %
  int batAnalog = analogRead(BAT_ADC_PIN);
  // Điện áp thực tế tại chân ADC (ESP32 ADC 0-3.3V tương ứng 0-4095)
  float vAdc = (batAnalog / 4095.0) * 3.3;
  // Cầu phân áp chia đôi nên điện áp pin thực tế vBat = vAdc * 2
  // Hiệu chuẩn thêm sai số diode/linh kiện (nếu có, ở đây nhân hệ số thực tế ~2.0)
  float vBat = vAdc * 2.0; 
  
  // Quy đổi ra dung lượng pin % cho pin 18650 (3.2V cạn - 4.2V đầy)
  int batPercent = map(vBat * 100, 320, 420, 0, 100);
  batPercent = constrain(batPercent, 0, 100);

  // 5. Đánh giá mức độ rủi ro sạt lở (Mô hình ngưỡng kết hợp TinyML logic)
  evaluateRiskLevel(soilPercent, rainPercent, tiltAngle, vibration);

  // Kích hoạt còi hú GPIO 25 khi NGUY HIỂM (cấp độ 2)
  updateBuzzer(currentAlertLevel);

  // 6. Hiển thị thông tin lên LCD 20x4
  updateLCD(soilPercent, rainPercent, vBat, currentAlertLevel);

  unsigned long currentTime = millis();

  // 7. In log cảm biến định kỳ (độc lập với LoRa — luôn hiện dù LoRa lỗi)
  if (currentTime - lastSerialLogTime >= SERIAL_LOG_INTERVAL) {
    printSerialDebug(soilPercent, rainPercent, tiltAngle, vibration, vBat, batPercent,
                     soilAnalog, rainAnalog, soilDigital, rainDigital);
    lastSerialLogTime = currentTime;
  }

  // 8. Gửi gói tin qua E32/AS32 (UART) theo chu kỳ
  if (loraReady && currentTime - lastLoraSendTime >= LORA_SEND_INTERVAL) {
    DataPacket packet;
    packet.soilMoisturePercent = soilPercent;
    packet.rainPercent = rainPercent;
    packet.tiltAngle = tiltAngle;
    packet.vibrationLevel = vibration;
    packet.batteryVoltage = vBat;
    packet.batteryPercent = batPercent;
    packet.alertLevel = currentAlertLevel;

    loraRadio.sendPacket(packet);
    lastLoraSendTime = currentTime;
  } else if (!loraReady && currentTime - lastLoraSendTime >= LORA_SEND_INTERVAL) {
    Serial.println("[LORA] OFF - E32 chua ket noi UART (xem log khoi dong).");
    lastLoraSendTime = currentTime;
  }

  delay(200); // Tần suất quét cảm biến
}

// Hàm đo và lưu góc cân bằng ban đầu của cọc quan trắc
void calibrateMPU() {
  Serial.println("[SYSTEM] Dang hieu chuan goc can bang cho MPU6050...");
  float sumPitch = 0;
  float sumRoll = 0;
  int samples = 50;

  for (int i = 0; i < samples; i++) {
    sensors_event_t a, g, temp;
    mpu.getEvent(&a, &g, &temp);
    float p = atan2(-a.acceleration.x, sqrt(a.acceleration.y * a.acceleration.y + a.acceleration.z * a.acceleration.z)) * 180.0 / M_PI;
    float r = atan2(a.acceleration.y, a.acceleration.z) * 180.0 / M_PI;
    sumPitch += p;
    sumRoll += r;
    delay(20);
  }

  basePitch = sumPitch / samples;
  baseRoll = sumRoll / samples;
  Serial.print("[SYSTEM] Goc can bang ban dau - Pitch: ");
  Serial.print(basePitch);
  Serial.print(" | Roll: ");
  Serial.println(baseRoll);
}

// Thuật toán đánh giá rủi ro (Kết hợp theo mô hình ngưỡng sạt lở)
void evaluateRiskLevel(float soil, float rain, float tilt, float vib) {
  // Cấp độ 2 (NGUY HIỂM - DANGER): Góc nghiêng vượt ngưỡng HOẶC (đất đã bão hòa nước cực cao kèm theo rung chấn mạnh/mưa rất to)
  if (tilt >= TILT_THRESHOLD_DEG || (soil >= 85.0 && vib >= VIBRATION_THRESHOLD)) {
    currentAlertLevel = 2;
  }
  // Cấp độ 1 (CẢNH BÁO SỚM - WARNING): Đất ẩm cao (>70%) và có mưa (>50%) hoặc có hiện tượng rung lắc nhẹ
  else if (soil >= 70.0 || rain >= 60.0 || vib >= 0.8) {
    currentAlertLevel = 1;
  }
  // Cấp độ 0 (AN TOÀN - SAFE): Các thông số ở dưới mức cảnh báo
  else {
    currentAlertLevel = 0;
  }
}

// Cập nhật giao diện màn hình LCD 20x4
void updateLCD(float soil, float rain, float vBat, uint8_t alert) {
  // Dòng 0: Hiển thị Đất và Mưa
  lcd.setCursor(0, 0);
  lcd.print("SOIL:");
  lcd.print((int)soil);
  lcd.print("%   ");
  
  lcd.setCursor(10, 0);
  lcd.print("RAIN:");
  lcd.print((int)rain);
  lcd.print("%   ");

  // Dòng 1: Hiển thị Góc nghiêng (hoặc độ nghiêng MPU6050 nếu có)
  lcd.setCursor(0, 1);
  if (mpuInitialized) {
    // Để đọc độ lệch góc nghiêng
    sensors_event_t a, g, temp;
    mpu.getEvent(&a, &g, &temp);
    float pitch = atan2(-a.acceleration.x, sqrt(a.acceleration.y * a.acceleration.y + a.acceleration.z * a.acceleration.z)) * 180.0 / M_PI;
    float roll = atan2(a.acceleration.y, a.acceleration.z) * 180.0 / M_PI;
    float deltaPitch = abs(pitch - basePitch);
    float deltaRoll = abs(roll - baseRoll);
    float tiltAngle = max(deltaPitch, deltaRoll);
    
    lcd.print("TILT:");
    lcd.print(tiltAngle, 1);
    lcd.print(" deg      ");
  } else {
    lcd.print("MPU6050: OFFLINE    ");
  }

  // Dòng 2: Hiển thị Dung lượng Pin
  lcd.setCursor(0, 2);
  lcd.print("BATTERY:");
  lcd.print(vBat, 2);
  lcd.print("V (");
  int batPercent = map(vBat * 100, 320, 420, 0, 100);
  batPercent = constrain(batPercent, 0, 100);
  lcd.print(batPercent);
  lcd.print("%)   ");

  // Dòng 3: Hiển thị trạng thái cảnh báo sạt lở
  lcd.setCursor(0, 3);
  if (alert == 2) {
    lcd.print("STATUS: > DANGER <  ");
  } else if (alert == 1) {
    lcd.print("STATUS: > WARNING < ");
  } else {
    lcd.print("STATUS: SAFE        ");
  }
}

// In thông tin giám sát ra Serial Monitor
void printSerialDebug(float soil, float rain, float tilt, float vib, float vBat, int batPct,
                      int soilRaw, int rainRaw, int soilDig, int rainDig) {
  Serial.println("----------------------------------------");
  Serial.printf("Do am dat: %.1f%% (ADC=%d, DO=%d)\n", soil, soilRaw, soilDig);
  Serial.printf("Luong mua: %.1f%% (ADC=%d, DO=%d)\n", rain, rainRaw, rainDig);
  Serial.printf("Do lech nghieng: %.2f do\n", tilt);
  Serial.printf("Rung dong: %.2f m/s2\n", vib);
  Serial.printf("Dien ap pin: %.2fV (%d%%)\n", vBat, batPct);
  Serial.print("Muc do canh bao: ");
  if (currentAlertLevel == 2) Serial.println("DANGER (NGUY HIEM - COI HU GPIO25)");
  else if (currentAlertLevel == 1) Serial.println("WARNING (CANH BAO)");
  else Serial.println("SAFE (AN TOAN)");
  Serial.printf("LoRa phat: %s\n", loraReady ? "BAT (gui moi 3s)" : "TAT (loi UART/module)");
}

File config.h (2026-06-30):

// config.h - configuration constants for Chong_Sat_Lo project

#ifndef CONFIG_H
#define CONFIG_H

// Wi‑Fi credentials – replace with your network details
#define WIFI_SSID "YourSSID"
#define WIFI_PASSWORD "YourPassword"

// SMTP settings – Gmail example (adjust if using different provider)
#define SMTP_SERVER "smtp.gmail.com"
#define SMTP_PORT 465 // TLS/SSL port
#define EMAIL_USER "your.email@gmail.com"      // Sender email address
#define EMAIL_PASS "your_app_password"        // App password or SMTP password
#define RECIPIENT_EMAIL "receiver@example.com" // Recipient for alerts

// Soil moisture sensor settings
#define MOISTURE_PIN 34               // Analog pin connected to sensor output
#define MOISTURE_THRESHOLD 1500      // Adjust after calibration (0‑4095 range)

// Alert timing
#define ALERT_INTERVAL_MS 1800000    // 30 minutes between alerts

#endif // CONFIG_H

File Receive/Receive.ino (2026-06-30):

/*
 * Receive.ino - Mạch thu LoRa (AS32 / EBYTE E32, UART)
 * Chi nhan RF va hien thi Serial + LCD — khong WiFi, khong web.
 *
 * - M0  -> GPIO 25
 * - M1  -> GPIO 26
 * - AUX -> GPIO 27
 * - RX  -> GPIO 16 (ESP32 RX2 <- TX module)
 * - TX  -> GPIO 17 (ESP32 TX2 -> RX module)
 * - LCD I2C: SDA=21, SCL=22
 */

#include <Wire.h>
#include <LiquidCrystal_I2C.h>
#include <LoRaLink.h>
#include <LoRaUartE32.h>

LoRaUartE32 loraE32;
LiquidCrystal_I2C lcd(0x27, 20, 4);

DataPacket latestData = {0};
unsigned long lastPacketTime = 0;
bool hasData = false;

uint8_t rxBuf[64];
size_t rxLen = 0;
unsigned long lastStatusTime = 0;

void updateLCD();

void onPacketReceived(const DataPacket& packet) {
  latestData = packet;
  lastPacketTime = millis();
  hasData = true;
  updateLCD();

  Serial.println("\n--- NHAN GOI TIN LORA ---");
  Serial.printf("Do am dat: %.1f%%\n", latestData.soilMoisturePercent);
  Serial.printf("Luong mua: %.1f%%\n", latestData.rainPercent);
  Serial.printf("Goc nghieng: %.2f do\n", latestData.tiltAngle);
  Serial.printf("Rung dong: %.2f m/s2\n", latestData.vibrationLevel);
  Serial.printf("Pin tram phat: %.2fV (%ld%%)\n", latestData.batteryVoltage, (long)latestData.batteryPercent);
  Serial.print("Canh bao: ");
  if (latestData.alertLevel == 2) Serial.println("NGUY HIEM");
  else if (latestData.alertLevel == 1) Serial.println("CANH BAO");
  else Serial.println("AN TOAN");
}

void processLoraUart() {
  while (loraE32.serial().available()) {
    if (rxLen >= sizeof(rxBuf)) {
      rxLen = 0;
    }
    rxBuf[rxLen++] = loraE32.serial().read();
  }

  if (rxLen == 0) {
    return;
  }

  DataPacket pkt;
  if (loraParseUartPayload(rxBuf, rxLen, pkt)) {
    onPacketReceived(pkt);
    rxLen = 0;
    return;
  }

  for (size_t i = 0; i < rxLen; i++) {
    if (rxBuf[i] != LORA_FRAME_MAGIC) {
      continue;
    }
    size_t remain = rxLen - i;
    if (remain < 1 + LORA_PACKET_SIZE) {
      if (i > 0) {
        memmove(rxBuf, rxBuf + i, remain);
        rxLen = remain;
      }
      return;
    }
    if (loraParseUartPayload(rxBuf + i, 1 + LORA_PACKET_SIZE, pkt)) {
      onPacketReceived(pkt);
      size_t consumed = i + 1 + LORA_PACKET_SIZE;
      memmove(rxBuf, rxBuf + consumed, rxLen - consumed);
      rxLen -= consumed;
      return;
    }
  }

  if (rxLen > sizeof(rxBuf) / 2) {
    rxLen = 0;
  }
}

void updateLCD() {
  lcd.clear();
  lcd.setCursor(0, 0);
  lcd.print("SOIL:");
  lcd.print((int)latestData.soilMoisturePercent);
  lcd.print("%  RAIN:");
  lcd.print((int)latestData.rainPercent);
  lcd.print("%");

  lcd.setCursor(0, 1);
  lcd.print("TILT:");
  lcd.print(latestData.tiltAngle, 1);
  lcd.print(" VIB:");
  lcd.print(latestData.vibrationLevel, 1);

  lcd.setCursor(0, 2);
  lcd.print("BAT:");
  lcd.print(latestData.batteryVoltage, 2);
  lcd.print("V ");
  lcd.print(latestData.batteryPercent);
  lcd.print("%");

  lcd.setCursor(0, 3);
  if (latestData.alertLevel == 2) {
    lcd.print("STATUS: DANGER    ");
  } else if (latestData.alertLevel == 1) {
    lcd.print("STATUS: WARNING   ");
  } else {
    lcd.print("STATUS: SAFE      ");
  }
}

void setup() {
  Serial.begin(9600);
  delay(500);
  Serial.println("\n--- MACH THU LORA (AS32/E32) ---");

  loraE32.begin();
  loraE32.configureModule();
  Serial.println("[SYSTEM] AS32 san sang nhan (9600bps, 433.125MHz).");
  Serial.println("[SYSTEM] Cho goi tin tu mach phat...");

  Wire.begin(21, 22);
  lcd.init();
  lcd.backlight();
  lcd.setCursor(0, 0);
  lcd.print("LORA RECEIVER     ");
  lcd.setCursor(0, 1);
  lcd.print("AS32/E32 UART     ");
  lcd.setCursor(0, 2);
  lcd.print("433MHz            ");
  lcd.setCursor(0, 3);
  lcd.print("Waiting RF...     ");

  lastStatusTime = millis();
}

void loop() {
  processLoraUart();

  if (millis() - lastStatusTime >= 10000) {
    lastStatusTime = millis();
    if (hasData) {
      unsigned long sec = (millis() - lastPacketTime) / 1000;
      Serial.printf("[STATUS] Da nhan du lieu | lan cuoi: %lu giay truoc\n", sec);
    } else {
      Serial.printf("[STATUS] Chua nhan goi tin | UART buffer: %u byte\n", (unsigned)rxLen);
      if (rxLen > 0) {
        Serial.print("[DEBUG] Raw: ");
        for (size_t i = 0; i < rxLen && i < 16; i++) {
          Serial.printf("%02X ", rxBuf[i]);
        }
        Serial.println();
      }
    }
  }

  static bool offlineWarned = false;
  if (hasData && (millis() - lastPacketTime > 15000)) {
    if (!offlineWarned) {
      offlineWarned = true;
      hasData = false;
      lcd.setCursor(0, 3);
      lcd.print("SIGNAL LOST!      ");
      Serial.println("[WARNING] Mat tin hieu LoRa > 15 giay.");
    }
  } else if (hasData) {
    offlineWarned = false;
  }

  delay(10);
}
